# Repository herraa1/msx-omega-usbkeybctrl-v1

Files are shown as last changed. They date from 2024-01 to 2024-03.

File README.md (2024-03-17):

# MSX Omega Home Computer USB Keyboard Controller PCB v1a

This is a rebuild of [Censlab's USB-keyboard-to-OMEGA-converter](https://github.com/Censlab/USB-keyboard-to-OMEGA-converter) using KiCad with some slight modifications.

> [!Note]
> Sillicony became Censlab on January 2024.

## Introduction

Censlab provides (thanks!) both the firmware and gerber files of his USB-keyboard-to-OMEGA-converter free for non-commercial use under the [cc-by-sa-4.0](https://creativecommons.org/licenses/by-sa/4.0/) license.

But if you need to make slight modifications to the adapter (mecanical tweaks, component size changes, connector additions, etc.) the gerber files are not suitable.
As the adapter hardware is small and with a few components, I decided to rebuild the adapter using KiCad to facilitate my own and future modifications.

## [Hardware](hardware/kicad/)

The original USB-keyboard-to-OMEGA-converter from Censlab is designed to snap directly to the Omega Computer keyboard port, thus it doesn't include installation holes.

|[](https://raw.githubusercontent.com/Censlab/USB-keyboard-to-OMEGA-converter/main/images/USB-Converter-3D.png) [](https://raw.githubusercontent.com/Censlab/USB-keyboard-to-OMEGA-converter/main/images/USBKeyboardtoOMEGA.jpg)|
|:--|
| Original USB-keyboard-to-OMEGA-converter from Censlab |

The adapter rebuild presented here adds the following minor modifications:
* generic installation holes (marked red in the image below)
  * can be used to attach the USB keyboard converter board anywhere
* specific two-hole configuration (marked green in the image below) to attach the USB keyboard converter board to the Omega Home Computer using two of the right side Omega main board holes
  * this simplifies installing the USB keyboard converter board on the Omega Home Computer when it collides with an internal CX-2 floppy drive controller HAT
* USB connector header (marked blue in the image below) that uses the same pinout of a PC USB header
  * this header enables the use of generic USB cables with panel mount USB connectors to easily bring the USB port to the outside of the computer case
  * this may be specially useful as the adapter is now compatible with several computers ([Omega](https://github.com/skiselev/omega), [JFF](https://github.com/konkotgit/JFF))
* silkscreen includes values for all components
* SMD component footprint sizes have been changed to 1206 to make manual soldering easier

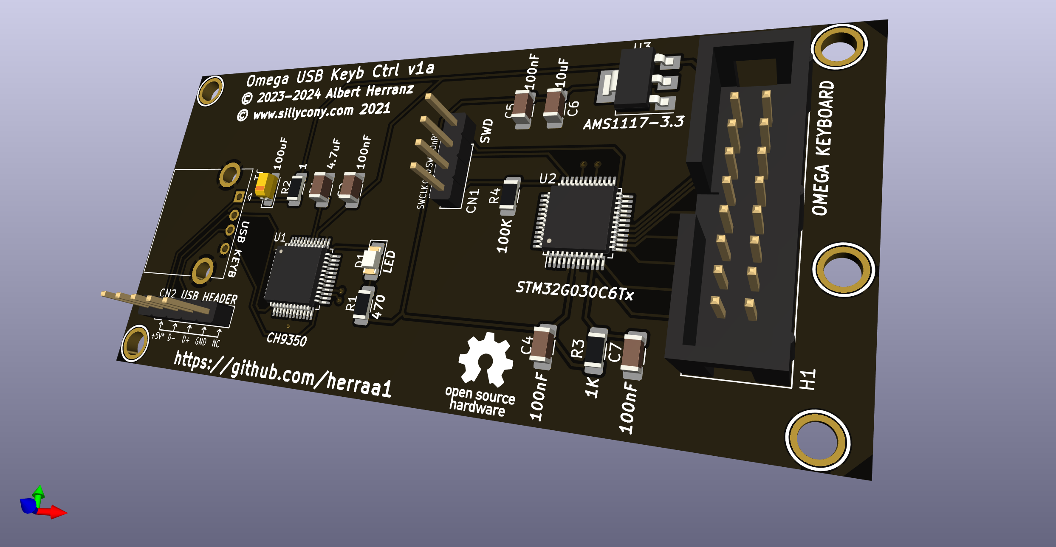
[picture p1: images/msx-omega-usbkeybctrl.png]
[](images/msx-omega-usbkeybctrl.png)

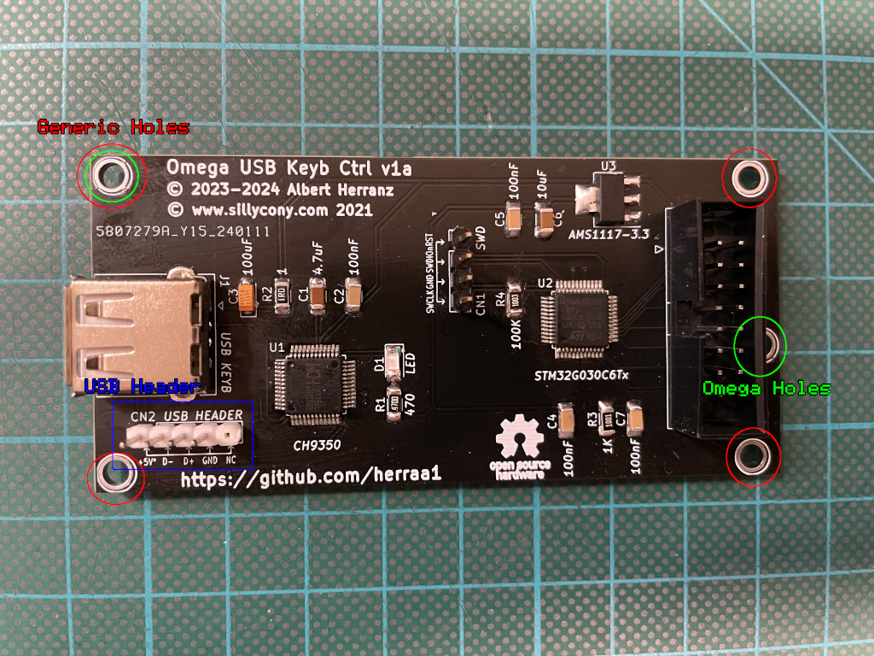
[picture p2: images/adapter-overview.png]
|[](images/adapter-overview.png)|
|:--|
| Modified USB Keyboard Controller |

## [Firmware](https://github.com/Censlab/USB-keyboard-to-OMEGA-converter/tree/main/elf)

This board uses the unmodified firmware provided by Censlab (thanks!) to implement the keyboard controller.

## Example installation on the Omega Home Computer main PCB

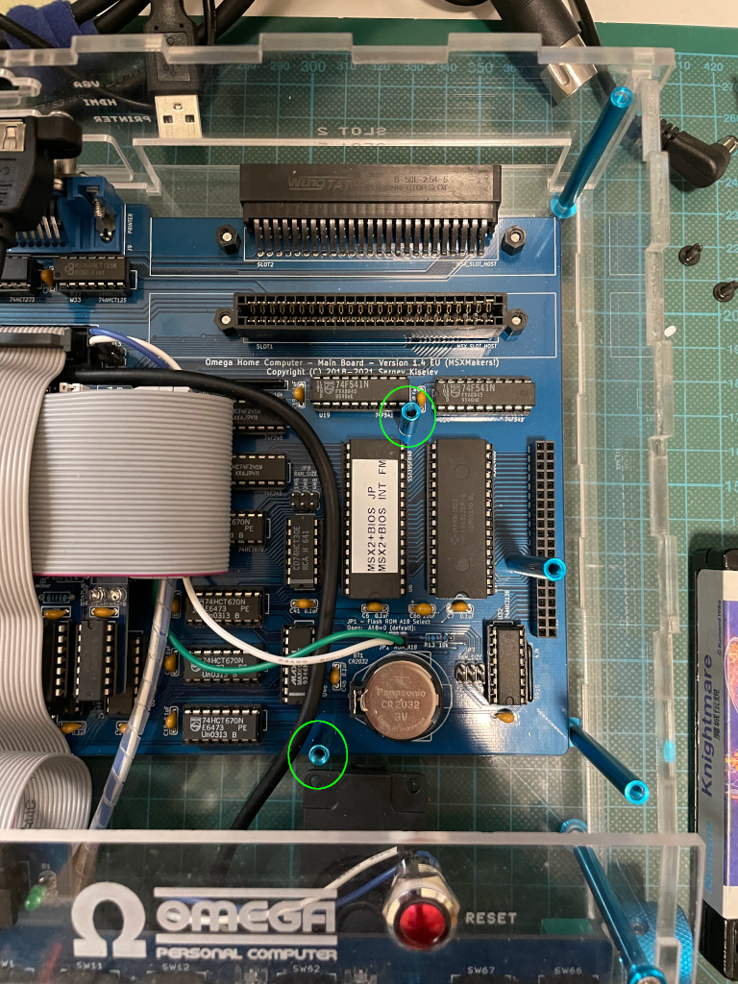
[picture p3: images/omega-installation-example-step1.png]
[](images/omega-installation-example-step1.png)
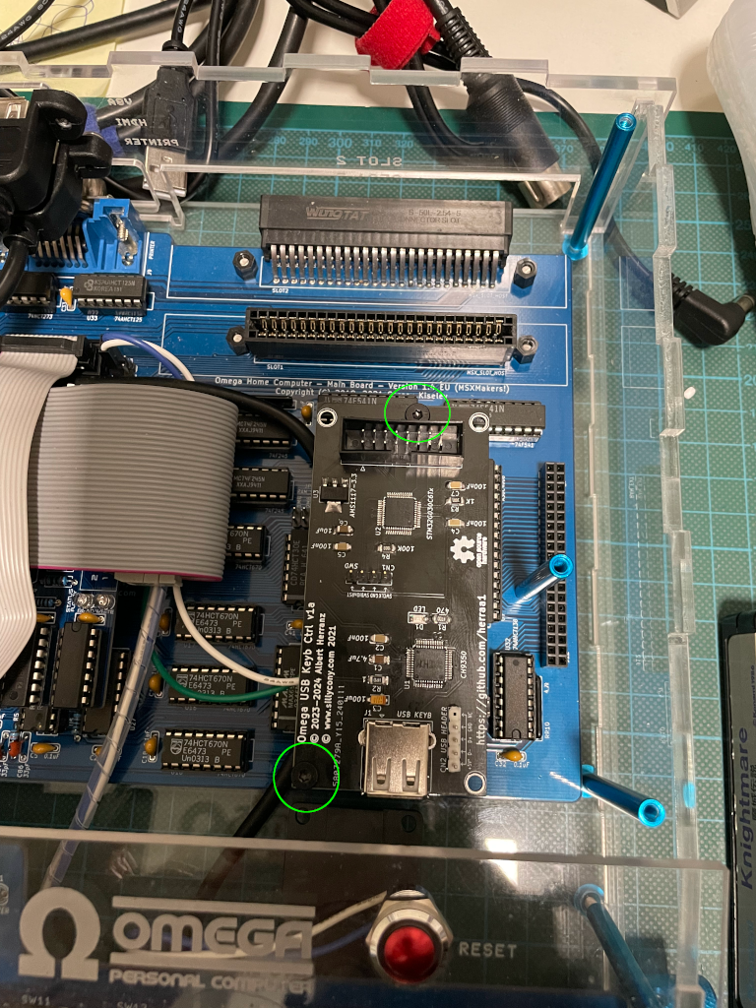
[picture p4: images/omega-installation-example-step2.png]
[](images/omega-installation-example-step2.png)
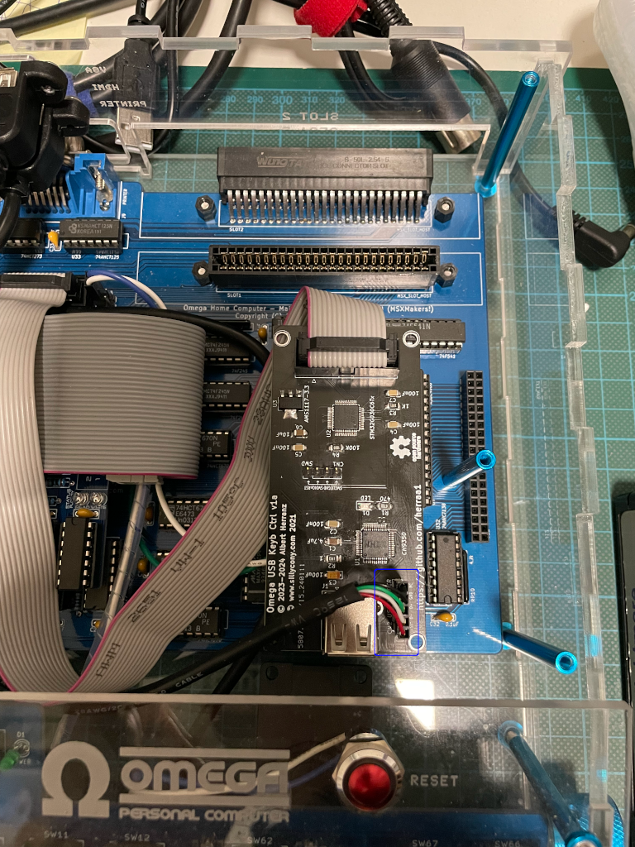
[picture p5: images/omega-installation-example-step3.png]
[](images/omega-installation-example-step3.png)

## References

Censlab USB-keyboard-to-OMEGA-converter
* https://github.com/Censlab/USB-keyboard-to-OMEGA-converter

MSX Makers! OMEGA USB KEYB CTRL build instructions
* https://msxmakers.design.blog/proyectos/omega-usb-keyb-ctrl/

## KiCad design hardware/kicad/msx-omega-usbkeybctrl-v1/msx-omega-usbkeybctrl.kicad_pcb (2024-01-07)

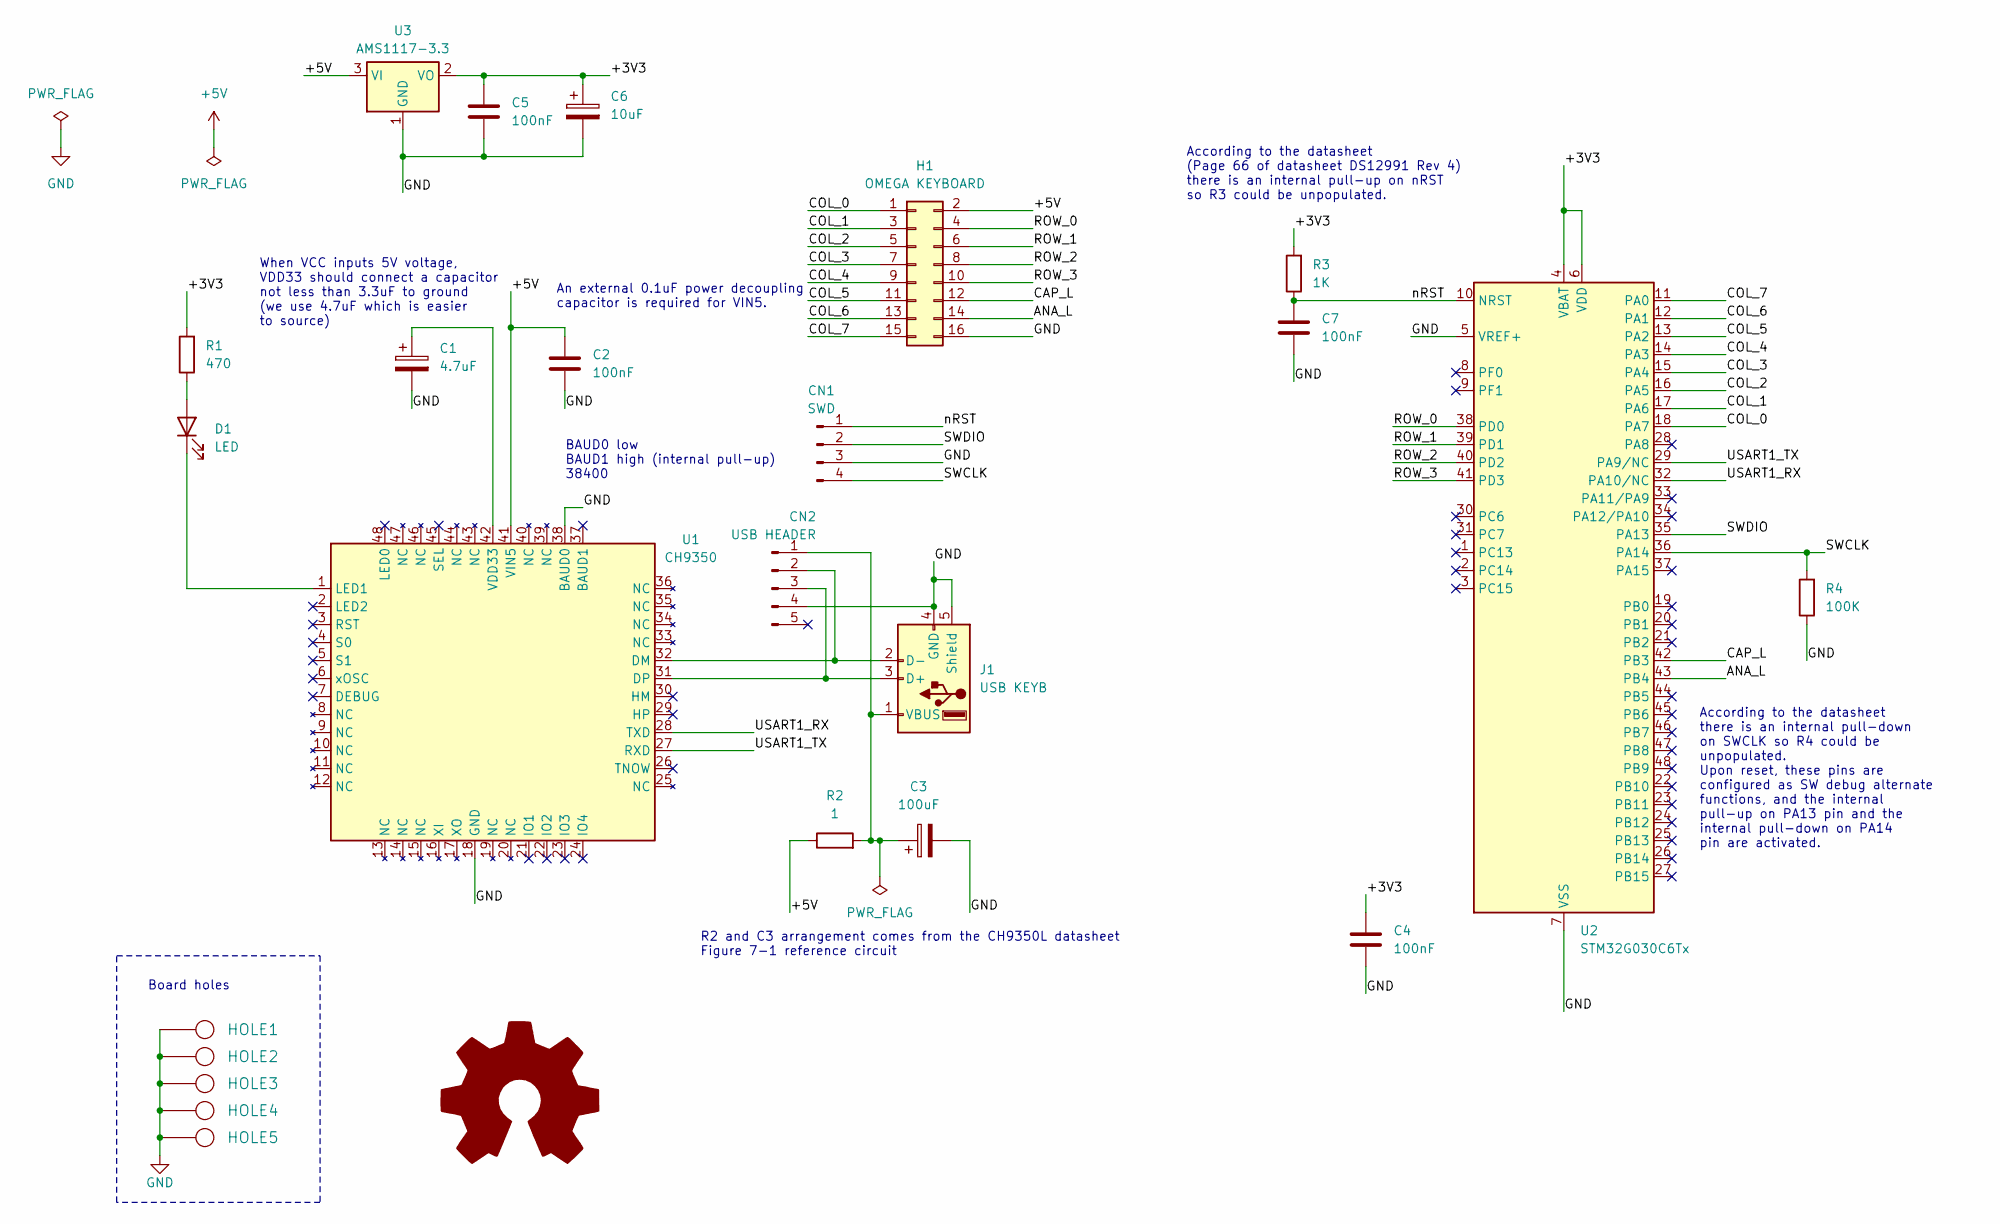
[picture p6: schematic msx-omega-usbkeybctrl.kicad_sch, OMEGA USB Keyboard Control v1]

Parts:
C1: 4.7uF; C_1206_3216Metric_Pad1.33x1.80mm_HandSolder
C2, C4, C5, C7: 100nF; C_1206_3216Metric_Pad1.33x1.80mm_HandSolder
C3: 100uF; CP_EIA-3216-18_Kemet-A_Pad1.58x1.35mm_HandSolder
C6: 10uF; C_1206_3216Metric_Pad1.33x1.80mm_HandSolder
CN1: SWD; PinHeader_1x04_P2.54mm_Vertical
CN2: USB HEADER; PinHeader_1x05_P2.54mm_Vertical
D1: LED; LED_1206_3216Metric_Pad1.42x1.75mm_HandSolder
H1: OMEGA KEYBOARD; IDC-Header_2x08_P2.54mm_Vertical
HOLE1, HOLE2, HOLE3, HOLE4, HOLE5: HOLE; Hole_3mm
J1: USB KEYB; USB_A_CONNFLY_DS1095-WNR0
R1: 470; R_1206_3216Metric_Pad1.30x1.75mm_HandSolder
R2: 1; R_1206_3216Metric_Pad1.30x1.75mm_HandSolder
R3: 1K; R_1206_3216Metric_Pad1.30x1.75mm_HandSolder
R4: 100K; R_1206_3216Metric_Pad1.30x1.75mm_HandSolder
SYM1: Logo_Open_Hardware_Large; OSHW-Logo_7.5x8mm_SilkScreen
U1: CH9350; LQFP-48_7x7mm_P0.5mm
U2: STM32G030C6Tx; LQFP-48_7x7mm_P0.5mm
U3: AMS1117-3.3; SOT-223-3_TabPin2

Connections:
+5V: C2.1, H1.2, R2.1, U1.41 (VIN5), U3.3 (VI)
/+3V3: C4.1, C5.1, C6.1, R1.2, R3.2, U2.4 (VBAT), U2.6 (VDD), U3.2 (VO)
/ANA_L: H1.14, U2.43 (PB4)
/CAP_L: H1.12, U2.42 (PB3)
/COL_0: H1.1, U2.18 (PA7)
/COL_1: H1.3, U2.17 (PA6)
/COL_2: H1.5, U2.16 (PA5)
/COL_3: H1.7, U2.15 (PA4)
/COL_4: H1.9, U2.14 (PA3)
/COL_5: H1.11, U2.13 (PA2)
/COL_6: H1.13, U2.12 (PA1)
/COL_7: H1.15, U2.11 (PA0)
/ROW_0: H1.4, U2.38 (PD0)
/ROW_1: H1.6, U2.39 (PD1)
/ROW_2: H1.8, U2.40 (PD2)
/ROW_3: H1.10, U2.41 (PD3)
/SWCLK: CN1.4, R4.2, U2.36 (PA14)
/SWDIO: CN1.2, U2.35 (PA13)
/USART1_RX: U1.28 (TXD), U2.32 (PA10/NC)
/USART1_TX: U1.27 (RXD), U2.29 (PA9/NC)
/nRST: C7.2, CN1.1, R3.1, U2.10 (NRST)
GND: C1.2, C2.2, C3.2, C4.2, C5.2, C6.2, C7.1, CN1.3, CN2.4, H1.16, HOLE1.1, HOLE2.1, HOLE3.1, HOLE4.1, HOLE5.1, J1.4 (GND), J1.5 (Shield), R4.1, U1.18 (GND), U1.38 (BAUD0), U2.5 (VREF+), U2.7 (VSS), U3.1 (GND)
unnamed: C3.1, CN2.1, J1.1 (VBUS), R2.2
unnamed: CN2.2, J1.2 (D-), U1.32 (DM)
unnamed: CN2.3, J1.3 (D+), U1.31 (DP)
unnamed: D1.2 (A), R1.1
unnamed: D1.1 (K), U1.1 (LED1)
unnamed: C1.1, U1.42 (VDD33)

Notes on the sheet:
According to the datasheet there is an internal pull-down on SWCLK so R4 could be unpopulated. Upon reset, these pins are configured as SW debug alternate functions, and the internal pull-up on PA13 pin and the internal pull-down on PA14 pin are activated.
BAUD0 low BAUD1 high (internal pull-up) 38400
R2 and C3 arrangement comes from the CH9350L datasheet Figure 7-1 reference circuit
An external 0.1uF power decoupling capacitor is required for VIN5.
When VCC inputs 5V voltage, VDD33 should connect a capacitor not less than 3.3uF to ground (we use 4.7uF which is easier to source)
Board holes
According to the datasheet (Page 66 of datasheet DS12991 Rev 4) there is an internal pull-up on nRST so R3 could be unpopulated.

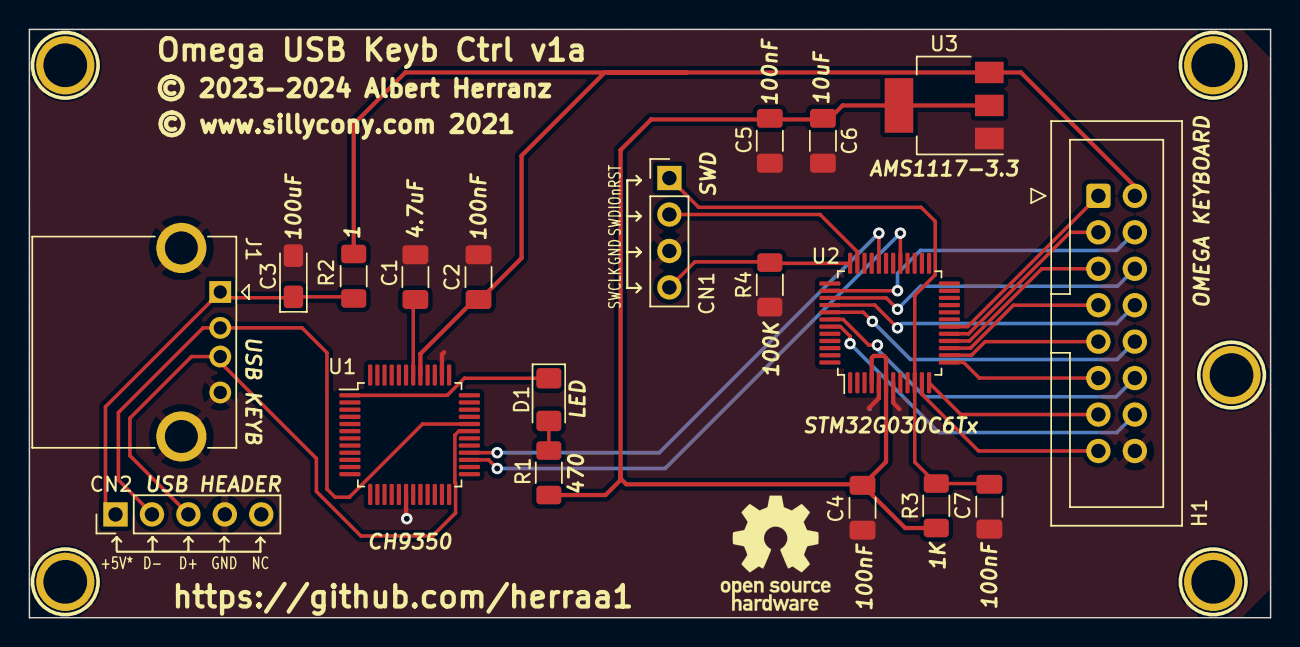
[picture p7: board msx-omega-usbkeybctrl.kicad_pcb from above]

Board: 2 copper layers, 86.5 x 41.0 mm, 25 parts (0 on the bottom side), 28 nets.

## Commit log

2024-01-07 Initial commit for v1a
    [msx-omega-usbkeybctrl-B_Cu.gbl, msx-omega-usbkeybctrl-B_Mask.gbs, msx-omega-usbkeybctrl-B_Paste.gbp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]
2024-01-28 add readme and gerbers

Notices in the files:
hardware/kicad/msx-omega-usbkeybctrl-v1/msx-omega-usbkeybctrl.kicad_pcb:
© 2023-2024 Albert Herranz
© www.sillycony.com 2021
